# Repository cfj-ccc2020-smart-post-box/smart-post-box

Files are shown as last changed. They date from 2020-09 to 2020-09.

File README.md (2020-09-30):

# Welcome to smart-post-box 👋










> Code for Japan - Civictech Challenge Cup 2020 Team:ARROW It's using ESP-32, Arduino, PlatformIO, Vue, PWA, Express, Slack, LINE, LINE-LIFF, TypeScript ...etc

### 🏠 [Homepage](https://github.com/cfj-ccc2020-smart-post-box/smart-post-box#readme)

### ✨ [Demo](https://youtu.be/A8zUHC4ug6E)

## Prerequisites

- node >=12.18.3
- yarn >=1.22.4

## Install

```sh
yarn install
```

## Usage

```sh
yarn run start
```

## Run tests

```sh
yarn run test
```

## Author

👤 **waricoma <waricoma@devne.co>**

* Website: https://3n38.app
* Twitter: [@waritocomatta](https://twitter.com/waritocomatta)
* Github: [@cfj-ccc2020-smart-post-box](https://github.com/cfj-ccc2020-smart-post-box)
* LinkedIn: [@motone-adachi-b92955145](https://linkedin.com/in/motone-adachi-b92955145)

## 🤝 Contributing

Contributions, issues and feature requests are welcome!

Feel free to check [issues page](https://github.com/cfj-ccc2020-smart-post-box/smart-post-box/issues). You can also take a look at the [contributing guide](https://github.com/cfj-ccc2020-smart-post-box/smart-post-box/blob/master/CONTRIBUTING.md).

## Show your support

Give a ⭐️ if this project helped you!

## 📝 License

Copyright © 2020 [waricoma <waricoma@devne.co>](https://github.com/cfj-ccc2020-smart-post-box).

This project is [GPL--2.0--only](https://github.com/cfj-ccc2020-smart-post-box/smart-post-box/blob/master/LICENSE) licensed.

***
_This README was generated with ❤️ by [readme-md-generator](https://github.com/kefranabg/readme-md-generator)_

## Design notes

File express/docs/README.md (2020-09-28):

**smart-post-box-express**

> README / [Globals](globals.md)

# Welcome to smart-post-box-express 👋








> smart-post-box-express

### 🏠 [Homepage](https://github.com/smart-post-box/smart-post-box#readme)

## Prerequisites

- node >=12.18.3
- yarn >=1.22.4

## Install

```sh
yarn install
```

## Usage

```sh
yarn run start
```

## Run tests

```sh
yarn run test
```

## Author

👤 **waricoma <waricoma@devne.co>**

* Website: https://www.wantedly.com/id/motone_adachi
* Twitter: [@waritocomatta](https://twitter.com/waritocomatta)
* Github: [@waricoma](https://github.com/waricoma)
* LinkedIn: [@motone-adachi-b92955145](https://linkedin.com/in/motone-adachi-b92955145)

## 🤝 Contributing

Contributions, issues and feature requests are welcome!

Feel free to check [issues page](https://github.com/smart-post-box/smart-post-box/issues). You can also take a look at the [contributing guide](https://github.com/smart-post-box/smart-post-box/blob/master/CONTRIBUTING.md).

## Show your support

Give a ⭐️ if this project helped you!

## 📝 License

Copyright © 2020 [waricoma <waricoma@devne.co>](https://github.com/waricoma).

This project is [GPL--2.0--only](https://github.com/smart-post-box/smart-post-box/blob/master/LICENSE) licensed.

***
_This README was generated with ❤️ by [readme-md-generator](https://github.com/kefranabg/readme-md-generator)_

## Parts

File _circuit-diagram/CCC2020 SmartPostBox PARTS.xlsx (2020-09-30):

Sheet: About
Rank | Model | Price: 0000 JPY | Processor | Sensor | Battery | Connection | Warning
Standard | SP-E-M-S-W | Price: 1458.65476190476 | ESP | Magnet | Small | WiFi | It's for the post box of having a lid. You need to prepare two AA size cells.
Standard | SP-E-I-S-W | Price: 1470.02380952381 | ESP | Infrared | Small | WiFi | You need to prepare two AA size cells.
Plus | SP-E-M-S-WM | Price: 2243.21428571429 | ESP | Magnet | Small | WiFi + Mobile Connection | It's for the post box of having a lid. You need to prepare the mobile router, 12V battery charger.
Plus | SP-E-I-S-WM | Price: 2258.39285714286 | ESP | Infrared | Small | WiFi + Mobile Connection | You need to prepare the mobile router, 12V battery charger.
Plus | SP-EM-I-S-W | Price: 3652.02380952381 | ESP+M5Camera | Infrared | Small | WiFi | You need to prepare two AA size cells.
Standard | SP-E-M-B-W | Price: 3661.11904761905 | ESP | Magnet | Big | WiFi | It's for the post box of having a lid. You need to prepare two AA size cells.
Standard | SP-E-I-B-W | Price: 3672.4880952381 | ESP | Infrared | Big | WiFi | You need to prepare two AA size cells.
Plus | SP-EM-M-S-W | Price: 3850.65476190476 | ESP+M5Camera | Magnet | Small | WiFi | It's for the post box of having a lid. You need to prepare two AA size cells.
Plus | SP-E-I-B-WM | Price: 4435.85714285714 | ESP | Infrared | Big | WiFi + Mobile Connection | You need to prepare the mobile router, 12V battery charger.
Pro | SP-EM-I-S-WM | Price: 4475.39285714286 | ESP+M5Camera | Infrared | Small | WiFi + Mobile Connection | You need to prepare the mobile router, 12V battery charger.
Plus | SP-E-M-B-WM | Price: 4480.67857142857 | ESP | Magnet | Big | WiFi + Mobile Connection | It's for the post box of having a lid. You need to prepare the mobile router, 12V battery charger.
Pro | SP-EM-M-S-WM | Price: 4495.21428571429 | ESP+M5Camera | Magnet | Small | WiFi + Mobile Connection | It's for the post box of having a lid. You need to prepare the mobile router, 12V battery charger.
Plus | SP-EM-M-B-W | Price: 5878.11904761905 | ESP+M5Camera | Magnet | Big | WiFi | It's for the post box of having a lid. You need to prepare two AA size cells.
Plus | SP-EM-I-B-W | Price: 5889.4880952381 | ESP+M5Camera | Infrared | Big | WiFi | You need to prepare two AA size cells.
Pro | SP-EM-M-B-WM | Price: 6587.67857142857 | ESP+M5Camera | Magnet | Big | WiFi + Mobile Connection | It's for the post box of having a lid. You need to prepare the mobile router, 12V battery charger.
Pro | SP-EM-I-B-WM | Price: 6602.85714285714 | ESP+M5Camera | Infrared | Big | WiFi + Mobile Connection | You need to prepare the mobile router, 12V battery charger.

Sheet: Parts categories
Body & Sensor
Sensor
Body
Mobile connection
Battery
Sensor & Mobile connection
Camera

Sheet: SP-E-M-S-W
Category | Goods name | Including parts count | Provider | A price of goods | Parts count | Price: 1458.65476190476 | Warning
Sensor | ﾘｰﾄﾞｽｲｯﾁ | 5 | https://akizukidenshi.com/catalog/g/gP-03676/ | 200 | 1 | 40
Body | ピンソケット | 42 | https://akizukidenshi.com/catalog/g/gC-05779/ | 80 | 22 | 41.9047619 | 20 this parts for ESP-WROOM-2, Two this parts for the sensor as body.
Sensor | ピンヘッダ | 40 | https://akizukidenshi.com/catalog/g/gC-00167/ | 35 | 2 | 1.75
Body | ESP-WROOM-2 | 1 | https://akizukidenshi.com/catalog/g/gK-12236/ | 1280 | 1 | 1280
Body | 基板 | 1 | https://akizukidenshi.com/catalog/g/gP-00517/ | 60 | 1 | 60
Battery | 単3電池ボックス | 1 | https://akizukidenshi.com/catalog/g/gP-10197/ | 35 | 1 | 35

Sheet: SP-E-M-S-WM
Category | Goods name | Including parts count | Provider | A price of goods | Parts count | Price: 2243.21428571429 | Warning
Sensor | ﾘｰﾄﾞｽｲｯﾁ | 5 | https://akizukidenshi.com/catalog/g/gP-03676/ | 200 | 1 | 40
Body & Sensor | ピンソケット | 42 | https://akizukidenshi.com/catalog/g/gC-05779/ | 80 | 24 | 45.71428571 | 20 this parts for ESP-WROOM-2, Two this parts for the sensor as body, Two this parts for the mobile connection as body.
Sensor & Mobile connection | ピンヘッダ | 40 | https://akizukidenshi.com/catalog/g/gC-00167/ | 35 | 4 | 3.5 | Two this parts for the sensor, Two this parts for the mobile connection.
Body | ESP-WROOM-2 | 1 | https://akizukidenshi.com/catalog/g/gK-12236/ | 1280 | 1 | 1280
Body | 基板 | 1 | https://akizukidenshi.com/catalog/g/gP-00517/ | 60 | 1 | 60
Mobile connection | ソレノイド | 1 | https://akizukidenshi.com/catalog/g/gP-10761/ | 450 | 1 | 450
Body | 昇圧回路 / USB Connector 単3電池ボックス | 1 | 100-yen shop | 110 | 1 | 110
Mobile connection | USB ケーブル | 1 | 100-yen shop | 110 | 1 | 110
Body | リレー | 1 | https://akizukidenshi.com/catalog/g/gP-07651/ | 60 | 2 | 120 | for mobile connection, Solenoid.
Body | ダイオード | 20 | https://akizukidenshi.com/catalog/g/gI-08327/ | 100 | 2 | 10 | for using relay.
Body | トランジスタ | 20 | https://akizukidenshi.com/catalog/g/gI-13491/ | 100 | 2 | 10 | for using relay.
Body | 10kΩ | 100 | https://akizukidenshi.com/catalog/g/gR-07838/ | 100 | 4 | 4 | for using relay.

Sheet: SP-E-M-B-W
Category | Goods name | Including parts count | Provider | A price of goods | Parts count | Price: 3661.11904761905 | Warning
Sensor | ﾘｰﾄﾞｽｲｯﾁ | 5 | https://akizukidenshi.com/catalog/g/gP-03676/ | 200 | 1 | 40
Body | ピンソケット | 42 | https://akizukidenshi.com/catalog/g/gC-05779/ | 80 | 25 | 47.61904762 | 20 this parts for ESP-WROOM-2, 3 this parts for the voltage down converter, Two this parts for the sensor as body.
Sensor | ピンヘッダ | 40 | https://akizukidenshi.com/catalog/g/gC-00167/ | 35 | 4 | 3.5 | Two this parts for the voltage down converter, Two this parts for the sensor.
Body | ESP-WROOM-2 | 1 | https://akizukidenshi.com/catalog/g/gK-12236/ | 1280 | 1 | 1280
Body | 基板 | 1 | https://akizukidenshi.com/catalog/g/gP-00517/ | 60 | 1 | 60
Battery | 鉛蓄電池 | 1 | https://akizukidenshi.com/catalog/g/gB-04961/ | 1600 | 1 | 1600
Battery | ファストン端子 | 1 | https://akizukidenshi.com/catalog/g/gC-13510/ | 10 | 2 | 20
Battery | 2.1mmプラグ | 1 | https://akizukidenshi.com/catalog/g/gC-02108/ | 60 | 1 | 60
Battery | 2.1mmジャック | 1 | https://akizukidenshi.com/catalog/g/gC-06342/ | 60 | 1 | 60
Battery | DCDC | 1 | https://akizukidenshi.com/catalog/g/gK-09981/ | 450 | 1 | 450
Battery | ヒートシンク | 1 | https://akizukidenshi.com/catalog/g/gP-05053/ | 40 | 1 | 40

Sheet: SP-E-M-B-WM
Category | Goods name | Including parts count | Provider | A price of goods | Parts count | Price: 4480.67857142857 | Warning
Sensor | ﾘｰﾄﾞｽｲｯﾁ | 5 | https://akizukidenshi.com/catalog/g/gP-03676/ | 200 | 1 | 40
Body | ピンソケット | 42 | https://akizukidenshi.com/catalog/g/gC-05779/ | 80 | 27 | 51.42857143 | 20 this parts for ESP-WROOM-2, 3 this parts for the voltage down converter, Two this parts for the sensor as body, Two this parts for the mobile connection as body.
Sensor & Mobile connection | ピンヘッダ | 40 | https://akizukidenshi.com/catalog/g/gC-00167/ | 35 | 6 | 5.25 | Two this parts for the sensor, Two this parts for the voltage down converter, Two this parts for the mobile connection.
Body | ESP-WROOM-2 | 1 | https://akizukidenshi.com/catalog/g/gK-12236/ | 1280 | 1 | 1280
Body | 基板 | 1 | https://akizukidenshi.com/catalog/g/gP-00517/ | 60 | 1 | 60
Battery | 鉛蓄電池 | 1 | https://akizukidenshi.com/catalog/g/gB-04961/ | 1600 | 1 | 1600
Battery | ファストン端子 | 1 | https://akizukidenshi.com/catalog/g/gC-13510/ | 10 | 2 | 20
Battery | 2.1mmプラグ | 1 | https://akizukidenshi.com/catalog/g/gC-02108/ | 60 | 1 | 60
Battery | 2.1mmジャック | 1 | https://akizukidenshi.com/catalog/g/gC-06342/ | 60 | 1 | 60
Battery | DCDC | 1 | https://akizukidenshi.com/catalog/g/gK-09981/ | 450 | 1 | 450
Battery | ヒートシンク | 1 | https://akizukidenshi.com/catalog/g/gP-05053/ | 40 | 1 | 40
Mobile connection | ソレノイド | 1 | https://akizukidenshi.com/catalog/g/gP-10761/ | 450 | 1 | 450
Body | 昇圧回路 / USBコネクタ | 1 | 100-yen shop | 110 | 1 | 110
Mobile connection | USB ケーブル | 1 | 100-yen shop | 110 | 1 | 110
Body | リレー | 1 | https://akizukidenshi.com/catalog/g/gP-07651/ | 60 | 2 | 120 | for mobile connection, Solenoid.
Body | ダイオード | 20 | https://akizukidenshi.com/catalog/g/gI-08327/ | 100 | 2 | 10 | for using relay.
Body | トランジスタ | 20 | https://akizukidenshi.com/catalog/g/gI-13491/ | 100 | 2 | 10 | for using relay.
Body | 10kΩ | 100 | https://akizukidenshi.com/catalog/g/gR-07838/ | 100 | 4 | 4 | for using relay.

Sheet: SP-E-I-S-W
Category | Goods name | Including parts count | Provider | A price of goods | Parts count | Price: 1470.02380952381 | Warning
Sensor | 赤外線LED | 5 | https://akizukidenshi.com/catalog/g/gI-03261/ | 100 | 1 | 20 | If your post box is large, We recommend changing the number of "Parts count" to 3. Because one sensor will be three sensors.
Sensor | フォトトランジスタ | 10 | https://akizukidenshi.com/catalog/g/gI-04213/ | 200 | 1 | 20 | If your post box is large, We recommend changing the number of ""Parts count"" to 3. Because one sensor will be three sensors.
Sensor | 抵抗50Ω | 100 | https://akizukidenshi.com/catalog/g/gR-07803/ | 100 | 1 | 1 | If your post box is large, We recommend changing the number of ""Parts count"" to 3. Because one sensor will be three sensors.
Sensor | 抵抗4.7kΩ | 100 | https://akizukidenshi.com/catalog/g/gR-07831/ | 100 | 1 | 1 | If your post box is large, We recommend changing the number of "Parts count" to 6. Because one sensor will be three sensors.
Body & Sensor | ピンソケット | 42 | https://akizukidenshi.com/catalog/g/gC-05779/ | 80 | 26 | 49.52380952 | 20 this parts for ESP-WROOM-2, 4 this parts for body, 4 this parts for one sensor. If your post box is large, We recommend changing the number of "Parts count" to 52. Because one sensor will be three sensors.
Sensor | ピンヘッダ | 40 | https://akizukidenshi.com/catalog/g/gC-00167/ | 35 | 4 | 3.5 | If your post box is large, We recommend changing the number of "Parts count" to 12. Because one sensor will be three sensors.
Body | ESP-WROOM-2 | 1 | https://akizukidenshi.com/catalog/g/gK-12236/ | 1280 | 1 | 1280
Body & Sensor | 基板 | 1 | https://akizukidenshi.com/catalog/g/gP-00517/ | 60 | 1 | 60 | If your post box is large, We recommend changing the number of ""Parts count"" to 2.
Battery | 単3電池ボックス | 1 | https://akizukidenshi.com/catalog/g/gP-10197/ | 35 | 1 | 35

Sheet: SP-E-I-S-WM
Category | Goods name | Including parts count | Provider | A price of goods | Parts count | Price: 2258.39285714286 | Warning
Sensor | 赤外線LED | 5 | https://akizukidenshi.com/catalog/g/gI-03261/ | 100 | 1 | 20 | If your post box is large, We recommend changing the number of "Parts count" to 3. Because one sensor will be three sensors.
Sensor | フォトトランジスタ | 10 | https://akizukidenshi.com/catalog/g/gI-04213/ | 200 | 1 | 20 | "If your post box is large, We recommend changing the number of ""Parts count"" to 3. Because one sensor will be three sensors."
Sensor | 抵抗50Ω | 100 | https://akizukidenshi.com/catalog/g/gR-07803/ | 100 | 1 | 1 | "If your post box is large, We recommend changing the number of ""Parts count"" to 3. Because one sensor will be three sensors."
Sensor | 抵抗4.7kΩ | 100 | https://akizukidenshi.com/catalog/g/gR-07831/ | 100 | 1 | 1 | If your post box is large, We recommend changing the number of "Parts count" to 6. Because one sensor will be three sensors.
Body & Sensor | ピンソケット | 42 | https://akizukidenshi.com/catalog/g/gC-05779/ | 80 | 30 | 57.14285714 | 20 this parts for ESP-WROOM-2, 4 this parts for body, 4 this parts for one sensor, two this parts for the mobile connection. If your post box is large, We recommend changing the number of "Parts count" to 54. Because one sensor will be three sensors.
Sensor & Mobile connection | ピンヘッダ | 40 | https://akizukidenshi.com/catalog/g/gC-00167/ | 35 | 6 | 5.25 | 4 this parts for the sensor, Two this parts for the mobile connection. If your post box is large, We recommend changing the number of "Parts count" to 14. Because one sensor will be three sensors.
Body | ESP-WROOM-2 | 1 | https://akizukidenshi.com/catalog/g/gK-12236/ | 1280 | 1 | 1280
Body & Sensor | 基板 | 1 | https://akizukidenshi.com/catalog/g/gP-00517/ | 60 | 1 | 60 | If your post box is large, We recommend changing the number of ""Parts count"" to 2.
Mobile connection | ソレノイド | 1 | https://akizukidenshi.com/catalog/g/gP-10761/ | 450 | 1 | 450
Body | 昇圧回路 / USB Connector 単3電池ボックス | 1 | 100-yen shop | 110 | 1 | 110
Mobile connection | USB Cable | 1 | 100-yen shop | 110 | 1 | 110
Body | リレー | 1 | https://akizukidenshi.com/catalog/g/gP-07651/ | 60 | 2 | 120 | for mobile connection, Solenoid.
Body | ダイオード | 20 | https://akizukidenshi.com/catalog/g/gI-08327/ | 100 | 2 | 10 | for using relay.
Body | トランジスタ | 20 | https://akizukidenshi.com/catalog/g/gI-13491/ | 100 | 2 | 10 | for using relay.
Body | 10kΩ | 100 | https://akizukidenshi.com/catalog/g/gR-07838/ | 100 | 4 | 4 | for using relay.

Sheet: SP-E-I-B-W
Category | Goods name | Including parts count | Provider | A price of goods | Parts count | Price: 3672.4880952381 | Warning
Sensor | 赤外線LED | 5 | https://akizukidenshi.com/catalog/g/gI-03261/ | 100 | 1 | 20 | If your post box is large, We recommend changing the number of "Parts count" to 3. Because one sensor will be three sensors.
Sensor | フォトトランジスタ | 10 | https://akizukidenshi.com/catalog/g/gI-04213/ | 200 | 1 | 20 | "If your post box is large, We recommend changing the number of ""Parts count"" to 3. Because one sensor will be three sensors."
Sensor | 抵抗50Ω | 100 | https://akizukidenshi.com/catalog/g/gR-07803/ | 100 | 1 | 1 | "If your post box is large, We recommend changing the number of ""Parts count"" to 3. Because one sensor will be three sensors."
Sensor | 抵抗4.7kΩ | 100 | https://akizukidenshi.com/catalog/g/gR-07831/ | 100 | 1 | 1 | If your post box is large, We recommend changing the number of "Parts count" to 6. Because one sensor will be three sensors.
Body & Sensor | ピンソケット | 42 | https://akizukidenshi.com/catalog/g/gC-05779/ | 80 | 29 | 55.23809524 | 20 this parts for ESP-WROOM-2, 4 this parts for body, 4 this parts for one sensor, 3 this parts for the voltage down converter. If your post box is large, We recommend changing the number of "Parts count" to 55. Because one sensor will be three sensors.
Body & Sensor | ピンヘッダ | 40 | https://akizukidenshi.com/catalog/g/gC-00167/ | 35 | 6 | 5.25 | Two this parts for the voltage down converter, 4 this parts for one sensor. If your post box is large, We recommend changing the number of "Parts count" to 14. Because one sensor will be three sensors.
Body | ESP-WROOM-2 | 1 | https://akizukidenshi.com/catalog/g/gK-12236/ | 1280 | 1 | 1280
Body & Sensor | 基板 | 1 | https://akizukidenshi.com/catalog/g/gP-00517/ | 60 | 1 | 60 | If your post box is large, We recommend changing the number of ""Parts count"" to 2.
Battery | 鉛蓄電池 | 1 | https://akizukidenshi.com/catalog/g/gB-04961/ | 1600 | 1 | 1600
Battery | ファストン端子 | 1 | https://akizukidenshi.com/catalog/g/gC-13510/ | 10 | 2 | 20
Battery | 2.1mmプラグ | 1 | https://akizukidenshi.com/catalog/g/gC-02108/ | 60 | 1 | 60
Battery | 2.1mmジャック | 1 | https://akizukidenshi.com/catalog/g/gC-06342/ | 60 | 1 | 60
Battery | DCDC | 1 | https://akizukidenshi.com/catalog/g/gK-09981/ | 450 | 1 | 450
Battery | ヒートシンク | 1 | https://akizukidenshi.com/catalog/g/gP-05053/ | 40 | 1 | 40

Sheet: SP-E-I-B-WM
Category | Goods name | Including parts count | Provider | A price of goods | Parts count | Price: 4435.85714285714 | Warning
Sensor | 赤外線LED | 5 | https://akizukidenshi.com/catalog/g/gI-03261/ | 100 | 1 | 20 | If your post box is large, We recommend changing the number of "Parts count" to 3. Because one sensor will be three sensors.
Sensor | フォトトランジスタ | 10 | https://akizukidenshi.com/catalog/g/gI-04213/ | 200 | 1 | 20 | If your post box is large, We recommend changing the number of ""Parts count"" to 3. Because one sensor will be three sensors.
Sensor | 抵抗50Ω | 100 | https://akizukidenshi.com/catalog/g/gR-07803/ | 100 | 1 | 1 | If your post box is large, We recommend changing the number of ""Parts count"" to 3. Because one sensor will be three sensors
Sensor | 抵抗4.7kΩ | 100 | https://akizukidenshi.com/catalog/g/gR-07831/ | 100 | 1 | 1 | If your post box is large, We recommend changing the number of "Parts count" to 6. Because one sensor will be three sensors.
Body & Sensor | ピンソケット | 42 | https://akizukidenshi.com/catalog/g/gC-05779/ | 80 | 33 | 62.85714286 | 20 this parts for ESP-WROOM-2, 4 this parts for body, 4 this parts for one sensor, Two this parts for the mobile connection, 3 this parts for the voltage down converter. If your post box is large, We recommend changing the number of "Parts count" to 57. Because one sensor will be three sensors.
Sensor & Mobile connection | ピンヘッダ | 40 | https://akizukidenshi.com/catalog/g/gC-00167/ | 35 | 8 | 7 | 4 this parts for the sensor, Two this parts for the mobile connection, Two this parts for the voltage down converter. If your post box is large, We recommend changing the number of "Parts count" to 16. Because one sensor will be three sensors.
Body | ESP-WROOM-2 | 1 | https://akizukidenshi.com/catalog/g/gK-12236/ | 1280 | 1 | 1280
Battery | 鉛蓄電池 | 1 | https://akizukidenshi.com/catalog/g/gB-04961/ | 1600 | 1 | 1600
Battery | ファストン端子 | 1 | https://akizukidenshi.com/catalog/g/gC-13510/ | 10 | 2 | 20
Body & Sensor | 基板 | 1 | https://akizukidenshi.com/catalog/g/gP-00517/ | 60 | 1 | 60 | If your post box is large, We recommend changing the number of ""Parts count"" to 2.
Battery | 2.1mmジャック | 1 | https://akizukidenshi.com/catalog/g/gC-06342/ | 60 | 1 | 60
Battery | DCDC | 1 | https://akizukidenshi.com/catalog/g/gK-09981/ | 450 | 1 | 450
Battery | ヒートシンク | 1 | https://akizukidenshi.com/catalog/g/gP-05053/ | 40 | 1 | 40
Mobile connection | ソレノイド | 1 | https://akizukidenshi.com/catalog/g/gP-10761/ | 450 | 1 | 450
Body | 昇圧回路 / USBコネクタ | 1 | 100-yen shop | 110 | 1 | 110
Mobile connection | USB ケーブル | 1 | 100-yen shop | 110 | 1 | 110
Body | リレー | 1 | https://akizukidenshi.com/catalog/g/gP-07651/ | 60 | 2 | 120 | for mobile connection, Solenoid.
Body | ダイオード | 20 | https://akizukidenshi.com/catalog/g/gI-08327/ | 100 | 2 | 10 | for using relay.
Body | トランジスタ | 20 | https://akizukidenshi.com/catalog/g/gI-13491/ | 100 | 2 | 10 | for using relay.
Body | 10kΩ | 100 | https://akizukidenshi.com/catalog/g/gR-07838/ | 100 | 4 | 4 | for using relay.

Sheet: SP-EM-M-S-W
Category | Goods name | Including parts count | Provider | A price of goods | Parts count | Price: 3850.65476190476 | Warning
Sensor | ﾘｰﾄﾞｽｲｯﾁ | 1 | https://akizukidenshi.com/catalog/g/gP-13371/ | 250 | 1 | 250
Body | ピンソケット | 42 | https://akizukidenshi.com/catalog/g/gC-05779/ | 80 | 22 | 41.9047619 | 20 this parts for ESP-WROOM-2, Two this parts for the sensor as body.
Sensor | ピンヘッダ | 40 | https://akizukidenshi.com/catalog/g/gC-00167/ | 35 | 2 | 1.75
Body | ESP-WROOM-2 | 1 | https://akizukidenshi.com/catalog/g/gK-12236/ | 1280 | 1 | 1280
Body | 基板 | 1 | https://akizukidenshi.com/catalog/g/gP-00517/ | 60 | 1 | 60
Body | 昇圧回路 / USB Connector 単3電池ボックス | 1 | 100-yen shop | 110 | 1 | 110
Camera | M5Camera | 1 | https://www.switch-science.com/catalog/5207/ | 2035 | 1 | 2035
Body | リレー | 1 | https://akizukidenshi.com/catalog/g/gP-07651/ | 60 | 1 | 60 | to control m5camera.
Body | ダイオード | 20 | https://akizukidenshi.com/catalog/g/gI-08327/ | 100 | 1 | 5 | for using relay.
Body | トランジスタ | 20 | https://akizukidenshi.com/catalog/g/gI-13491/ | 100 | 1 | 5 | for using relay.
Body | 10kΩ | 100 | https://akizukidenshi.com/catalog/g/gR-07838/ | 100 | 2 | 2 | for using relay.

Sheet: SP-EM-M-S-WM
Category | Goods name | Including parts count | Provider | A price of goods | Parts count | Price: 4495.21428571429 | Warning
Sensor | ﾘｰﾄﾞｽｲｯﾁ | 5 | https://akizukidenshi.com/catalog/g/gP-03676/ | 200 | 1 | 40
Body & Sensor | ピンソケット | 42 | https://akizukidenshi.com/catalog/g/gC-05779/ | 80 | 24 | 45.71428571 | 20 this parts for ESP-WROOM-2, Two this parts for the sensor as body, Two this parts for the mobile connection as body.
Sensor & Mobile connection | ピンヘッダ | 40 | https://akizukidenshi.com/catalog/g/gC-00167/ | 35 | 4 | 3.5 | Two this parts for the sensor, Two this parts for the mobile connection.
Body | ESP-WROOM-2 | 1 | https://akizukidenshi.com/catalog/g/gK-12236/ | 1280 | 1 | 1280
Body | 基板 | 1 | https://akizukidenshi.com/catalog/g/gP-00517/ | 60 | 1 | 60
Battery | 単3電池ボックス | 1 | https://akizukidenshi.com/catalog/g/gP-10197/ | 35 | 1 | 35
Mobile connection | ソレノイド | 1 | https://akizukidenshi.com/catalog/g/gP-10761/ | 450 | 1 | 450
Body | 昇圧回路 / USB Connector | 1 | 100-yen shop | 110 | 2 | 220 | for mobile connection, M5camera.
Mobile connection | USB ケーブル | 1 | 100-yen shop | 110 | 1 | 110
Camera | M5Camera | 1 | https://www.switch-science.com/catalog/5207/ | 2035 | 1 | 2035
Body | リレー | 1 | https://akizukidenshi.com/catalog/g/gP-07651/ | 60 | 3 | 180 | for mobile connection, Solenoid, M5camera.
Body | ダイオード | 20 | https://akizukidenshi.com/catalog/g/gI-08327/ | 100 | 3 | 15 | for using relay.
Body | トランジスタ | 20 | https://akizukidenshi.com/catalog/g/gI-13491/ | 100 | 3 | 15 | for using relay.
Body | 10kΩ | 100 | https://akizukidenshi.com/catalog/g/gR-07838/ | 100 | 6 | 6 | for using relay.

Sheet: SP-EM-M-B-W
Category | Goods name | Including parts count | Provider | A price of goods | Parts count | Price: 5878.11904761905 | Warning
Sensor | ﾘｰﾄﾞｽｲｯﾁ | 5 | https://akizukidenshi.com/catalog/g/gP-03676/ | 200 | 1 | 40
Body | ピンソケット | 42 | https://akizukidenshi.com/catalog/g/gC-05779/ | 80 | 25 | 47.61904762 | 20 this parts for ESP-WROOM-2, 3 this parts for the voltage down converter, Two this parts for the sensor as body.
Sensor | ピンヘッダ | 40 | https://akizukidenshi.com/catalog/g/gC-00167/ | 35 | 4 | 3.5 | Two this parts for the voltage down converter, Two this parts for the sensor.
Body | ESP-WROOM-2 | 1 | https://akizukidenshi.com/catalog/g/gK-12236/ | 1280 | 1 | 1280
Body | 基板 | 1 | https://akizukidenshi.com/catalog/g/gP-00517/ | 60 | 1 | 60
Battery | 鉛蓄電池 | 1 | https://akizukidenshi.com/catalog/g/gB-04961/ | 1600 | 1 | 1600
Battery | ファストン端子 | 1 | https://akizukidenshi.com/catalog/g/gC-13510/ | 10 | 2 | 20
Battery | 2.1mmプラグ | 1 | https://akizukidenshi.com/catalog/g/gC-02108/ | 60 | 1 | 60
Battery | 2.1mmジャック | 1 | https://akizukidenshi.com/catalog/g/gC-06342/ | 60 | 1 | 60
Battery | DCDC | 1 | https://akizukidenshi.com/catalog/g/gK-09981/ | 450 | 1 | 450
Battery | ヒートシンク | 1 | https://akizukidenshi.com/catalog/g/gP-05053/ | 40 | 1 | 40
Camera | M5Camera | 1 | https://www.switch-science.com/catalog/5207/ | 2035 | 1 | 2035
Body | 昇圧回路 / USB Connector | 1 | 100-yen shop | 110 | 1 | 110
Body | リレー | 1 | https://akizukidenshi.com/catalog/g/gP-07651/ | 60 | 1 | 60 | to control m5camera.
Body | ダイオード | 20 | https://akizukidenshi.com/catalog/g/gI-08327/ | 100 | 1 | 5 | for using relay.
Body | トランジスタ | 20 | https://akizukidenshi.com/catalog/g/gI-13491/ | 100 | 1 | 5 | for using relay.
Body | 10kΩ | 100 | https://akizukidenshi.com/catalog/g/gR-07838/ | 100 | 2 | 2 | for using relay.

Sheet: SP-EM-M-B-WM
Category | Goods name | Including parts count | Provider | A price of goods | Parts count | Price: 6587.67857142857 | Warning
Sensor | ﾘｰﾄﾞｽｲｯﾁ | 5 | https://akizukidenshi.com/catalog/g/gP-03676/ | 200 | 1 | 40
Body | ピンソケット | 42 | https://akizukidenshi.com/catalog/g/gC-05779/ | 80 | 27 | 51.42857143 | 20 this parts for ESP-WROOM-2, 3 this parts for the voltage down converter, Two this parts for the sensor as body, Two this parts for the mobile connection as body.
Sensor & Mobile connection | ピンヘッダ | 40 | https://akizukidenshi.com/catalog/g/gC-00167/ | 35 | 6 | 5.25 | Two this parts for the sensor, Two this parts for the voltage down converter, Two this parts for the mobile connection.
Body | ESP-WROOM-2 | 1 | https://akizukidenshi.com/catalog/g/gK-12236/ | 1280 | 1 | 1280
Body | 基板 | 1 | https://akizukidenshi.com/catalog/g/gP-00517/ | 60 | 1 | 60
Battery | 鉛蓄電池 | 1 | https://akizukidenshi.com/catalog/g/gB-04961/ | 1600 | 1 | 1600
Battery | ファストン端子 | 1 | https://akizukidenshi.com/catalog/g/gC-13510/ | 10 | 2 | 20
Battery | 2.1mmプラグ | 1 | https://akizukidenshi.com/catalog/g/gC-02108/ | 60 | 1 | 60
Battery | 2.1mmジャック | 1 | https://akizukidenshi.com/catalog/g/gC-06342/ | 60 | 1 | 60
Battery | DCDC | 1 | https://akizukidenshi.com/catalog/g/gK-09981/ | 450 | 1 | 450
Battery | ヒートシンク | 1 | https://akizukidenshi.com/catalog/g/gP-05053/ | 40 | 1 | 40
Mobile connection | ソレノイド | 1 | https://akizukidenshi.com/catalog/g/gP-10761/ | 450 | 1 | 450
Body | USBハブ | 1 | 100-yen shop | 110 | 1 | 110 | for mobile connection, M5camera.
Mobile connection | USB ケーブル | 1 | 100-yen shop | 110 | 1 | 110
Camera | M5Camera | 1 | https://www.switch-science.com/catalog/5207/ | 2035 | 1 | 2035
Body | リレー | 1 | https://akizukidenshi.com/catalog/g/gP-07651/ | 60 | 3 | 180 | for mobile connection, Solenoid, M5camera.
Body | ダイオード | 20 | https://akizukidenshi.com/catalog/g/gI-08327/ | 100 | 3 | 15 | for using relay.
Body | トランジスタ | 20 | https://akizukidenshi.com/catalog/g/gI-13491/ | 100 | 3 | 15 | for using relay.
Body | 10kΩ | 100 | https://akizukidenshi.com/catalog/g/gR-07838/ | 100 | 6 | 6 | for using relay.

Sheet: SP-EM-I-S-W
Category | Goods name | Including parts count | Provider | A price of goods | Parts count | Price: 3652.02380952381 | Warning
Sensor | 赤外線LED | 5 | https://akizukidenshi.com/catalog/g/gI-03261/ | 100 | 1 | 20 | If your post box is large, We recommend changing the number of "Parts count" to 3. Because one sensor will be three sensors.
Sensor | フォトトランジスタ | 10 | https://akizukidenshi.com/catalog/g/gI-04213/ | 200 | 1 | 20 | "If your post box is large, We recommend changing the number of ""Parts count"" to 3. Because one sensor will be three sensors."
Sensor | 抵抗50Ω | 100 | https://akizukidenshi.com/catalog/g/gR-07803/ | 100 | 1 | 1 | "If your post box is large, We recommend changing the number of ""Parts count"" to 3. Because one sensor will be three sensors."
Sensor | 抵抗4.7kΩ | 100 | https://akizukidenshi.com/catalog/g/gR-07831/ | 100 | 1 | 1 | If your post box is large, We recommend changing the number of "Parts count" to 6. Because one sensor will be three sensors.
Body & Sensor | ピンソケット | 42 | https://akizukidenshi.com/catalog/g/gC-05779/ | 80 | 26 | 49.52380952 | 20 this parts for ESP-WROOM-2, 4 this parts for body, 4 this parts for one sensor. If your post box is large, We recommend changing the number of "Parts count" to 52. Because one sensor will be three sensors.
Sensor | ピンヘッダ | 40 | https://akizukidenshi.com/catalog/g/gC-00167/ | 35 | 4 | 3.5 | If your post box is large, We recommend changing the number of "Parts count" to 12. Because one sensor will be three sensors.
Body | ESP-WROOM-2 | 1 | https://akizukidenshi.com/catalog/g/gK-12236/ | 1280 | 1 | 1280
Body | 昇圧回路 / USB Connector 単3電池ボックス | 1 | 100-yen shop | 110 | 1 | 110
Camera | M5Camera | 1 | https://www.switch-science.com/catalog/5207/ | 2035 | 1 | 2035
Body & Sensor | 基板 | 1 | https://akizukidenshi.com/catalog/g/gP-00517/ | 60 | 1 | 60 | If your post box is large, We recommend changing the number of ""Parts count"" to 2.
Body | リレー | 1 | https://akizukidenshi.com/catalog/g/gP-07651/ | 60 | 1 | 60 | to control m5camera.
Body | ダイオード | 20 | https://akizukidenshi.com/catalog/g/gI-08327/ | 100 | 1 | 5 | for using relay.
Body | トランジスタ | 20 | https://akizukidenshi.com/catalog/g/gI-13491/ | 100 | 1 | 5 | for using relay.
Body | 10kΩ | 100 | https://akizukidenshi.com/catalog/g/gR-07838/ | 100 | 2 | 2 | for using relay.

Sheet: SP-EM-I-S-WM
Category | Goods name | Including parts count | Provider | A price of goods | Parts count | Price: 4475.39285714286 | Warning
Sensor | 赤外線LED | 5 | https://akizukidenshi.com/catalog/g/gI-03261/ | 100 | 1 | 20 | If your post box is large, We recommend changing the number of "Parts count" to 3. Because one sensor will be three sensors.
Sensor | フォトトランジスタ | 10 | https://akizukidenshi.com/catalog/g/gI-04213/ | 200 | 1 | 20 | "If your post box is large, We recommend changing the number of ""Parts count"" to 3. Because one sensor will be three sensors."
Sensor | 抵抗50Ω | 100 | https://akizukidenshi.com/catalog/g/gR-07803/ | 100 | 1 | 1 | "If your post box is large, We recommend changing the number of ""Parts count"" to 3. Because one sensor will be three sensors."
Sensor | 抵抗4.7kΩ | 100 | https://akizukidenshi.com/catalog/g/gR-07831/ | 100 | 1 | 1 | If your post box is large, We recommend changing the number of "Parts count" to 6. Because one sensor will be three sensors.
Body & Sensor | ピンソケット | 42 | https://akizukidenshi.com/catalog/g/gC-05779/ | 80 | 30 | 57.14285714 | 20 this parts for ESP-WROOM-2, 4 this parts for body, 4 this parts for one sensor, two this parts for the mobile connection. If your post box is large, We recommend changing the number of "Parts count" to 54. Because one sensor will be three sensors.
Sensor & Mobile connection | ピンヘッダ | 40 | https://akizukidenshi.com/catalog/g/gC-00167/ | 35 | 6 | 5.25 | 4 this parts for the sensor, Two this parts for the mobile connection. If your post box is large, We recommend changing the number of "Parts count" to 14. Because one sensor will be three sensors.
Body | ESP-WROOM-2 | 1 | https://akizukidenshi.com/catalog/g/gK-12236/ | 1280 | 1 | 1280
Body & Sensor | 基板 | 1 | https://akizukidenshi.com/catalog/g/gP-00517/ | 60 | 1 | 60 | If your post box is large, We recommend changing the number of ""Parts count"" to 2.
Mobile connection | ソレノイド | 1 | https://akizukidenshi.com/catalog/g/gP-10761/ | 450 | 1 | 450
Body | 昇圧回路 / USB Connector 単3電池ボックス | 1 | 100-yen shop | 110 | 2 | 220 | for mobile connection, M5camera.
Mobile connection | USB Cable | 1 | 100-yen shop | 110 | 1 | 110
Camera | M5Camera | 1 | https://www.switch-science.com/catalog/5207/ | 2035 | 1 | 2035
Body | リレー | 1 | https://akizukidenshi.com/catalog/g/gP-07651/ | 60 | 3 | 180 | for mobile connection, Solenoid, M5camera.
Body | ダイオード | 20 | https://akizukidenshi.com/catalog/g/gI-08327/ | 100 | 3 | 15 | for using relay.
Body | トランジスタ | 20 | https://akizukidenshi.com/catalog/g/gI-13491/ | 100 | 3 | 15 | for using relay.
Body | 10kΩ | 100 | https://akizukidenshi.com/catalog/g/gR-07838/ | 100 | 6 | 6 | for using relay.
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

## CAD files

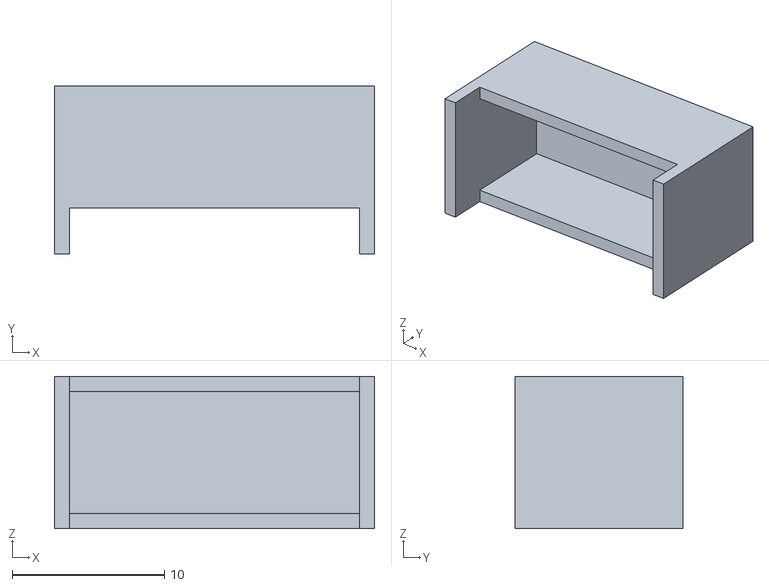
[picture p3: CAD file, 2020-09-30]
_3d-cad/fillParts/underESPSuppress.stl
21.0 x 11.0 x 10.0

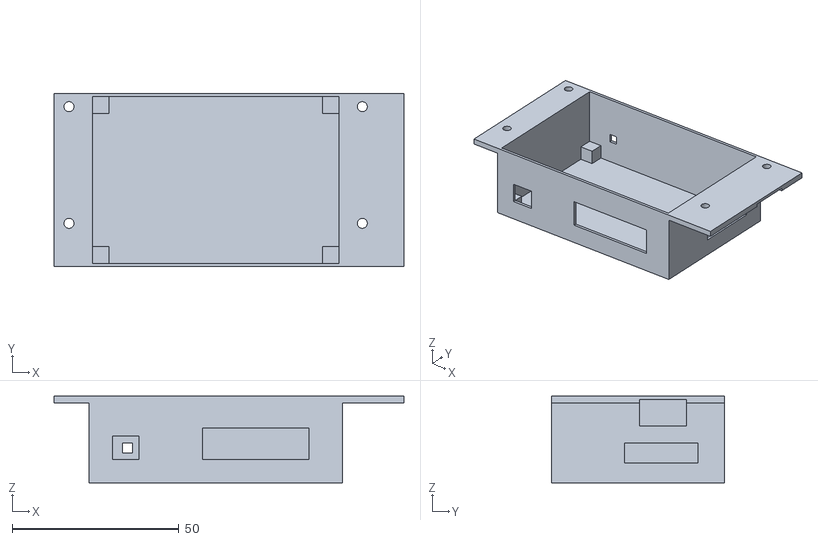
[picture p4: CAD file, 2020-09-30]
_3d-cad/mainbox/box.stl
105.0 x 52.0 x 26.0

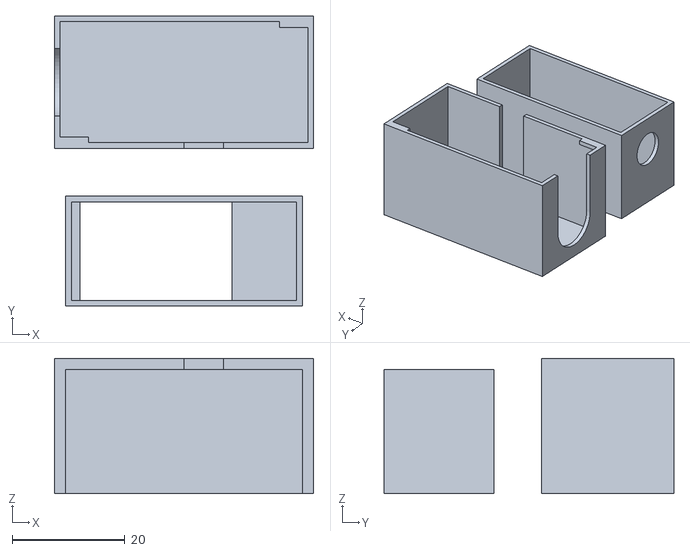
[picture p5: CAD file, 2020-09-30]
_3d-cad/subBox/DCDC.stl
46.0 x 51.5 x 24.0

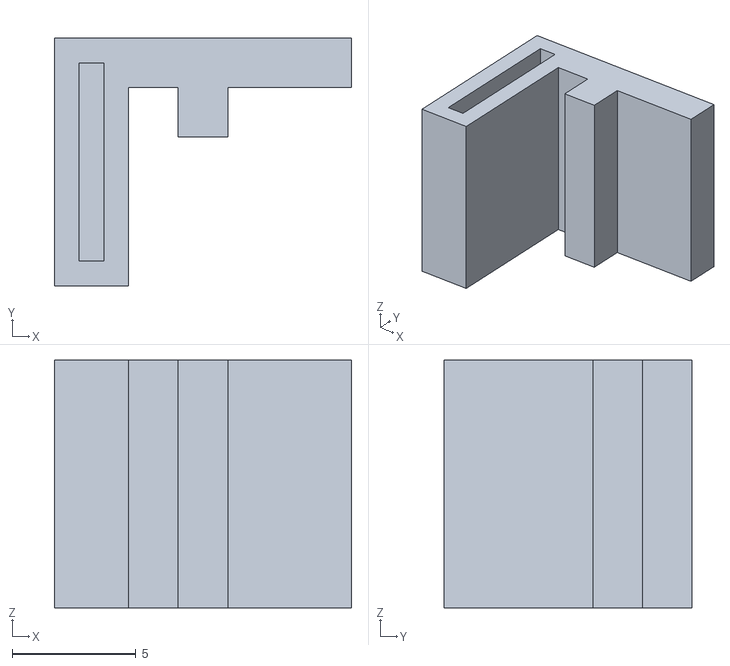
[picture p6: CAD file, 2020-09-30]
_3d-cad/fillParts/lock.stl
12.0 x 10.0 x 10.0

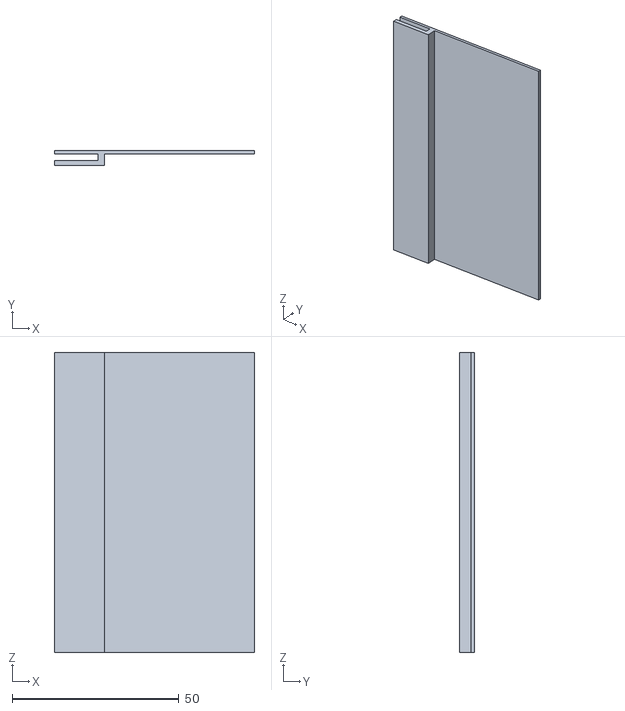
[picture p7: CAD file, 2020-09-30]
_3d-cad/mainbox/roof9.stl
60.0 x 4.50 x 90.0

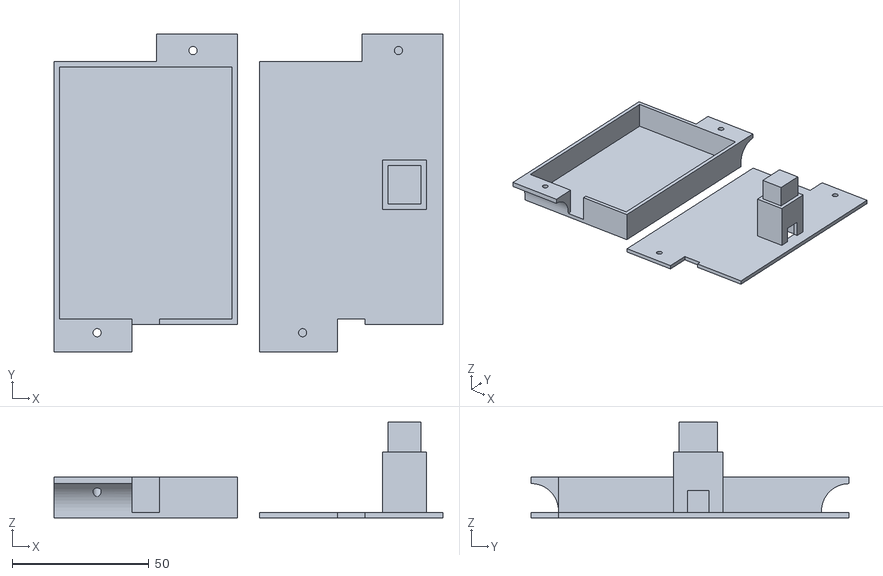
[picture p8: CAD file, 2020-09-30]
_3d-cad/subBox/roter.stl
142.0 x 116.0 x 35.0

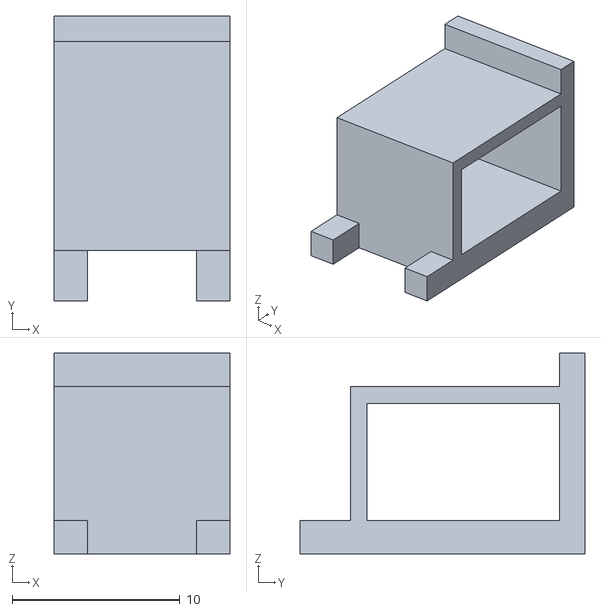
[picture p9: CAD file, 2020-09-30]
_3d-cad/fillParts/2Suppress.stl
10.5 x 17.0 x 12.0

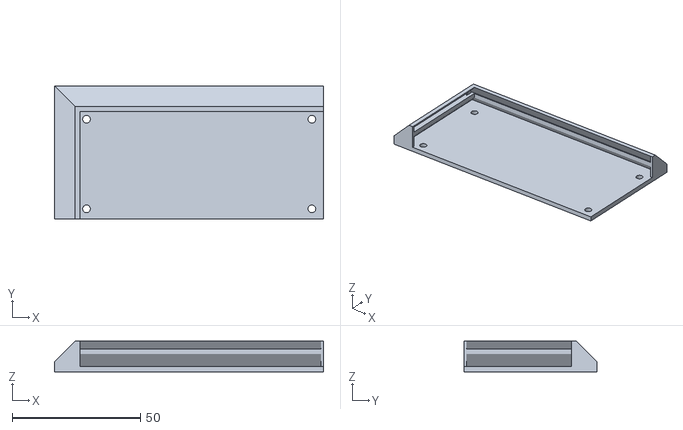
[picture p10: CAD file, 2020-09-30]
_3d-cad/mainbox/cover.stl
105.0 x 52.0 x 12.0

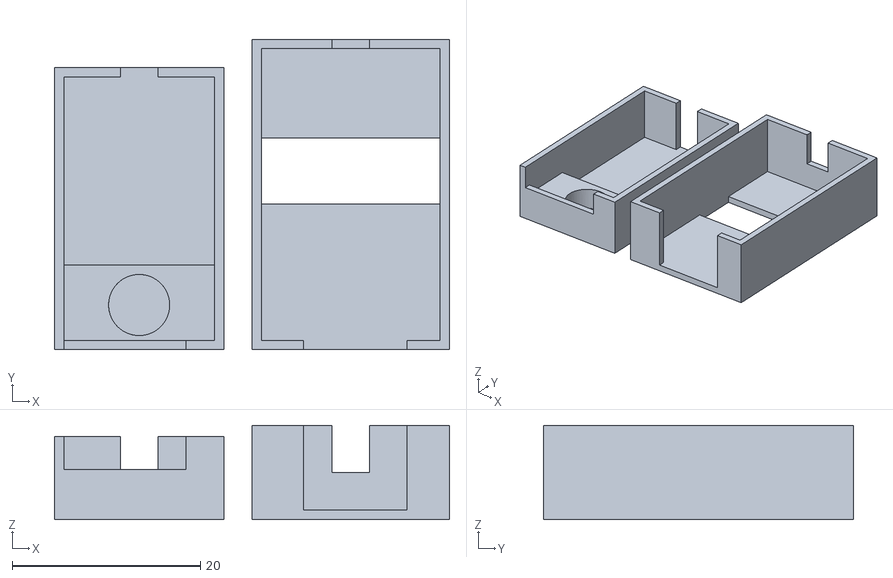
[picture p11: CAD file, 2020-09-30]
_3d-cad/subBox/LED.stl
42.0 x 33.0 x 10.0

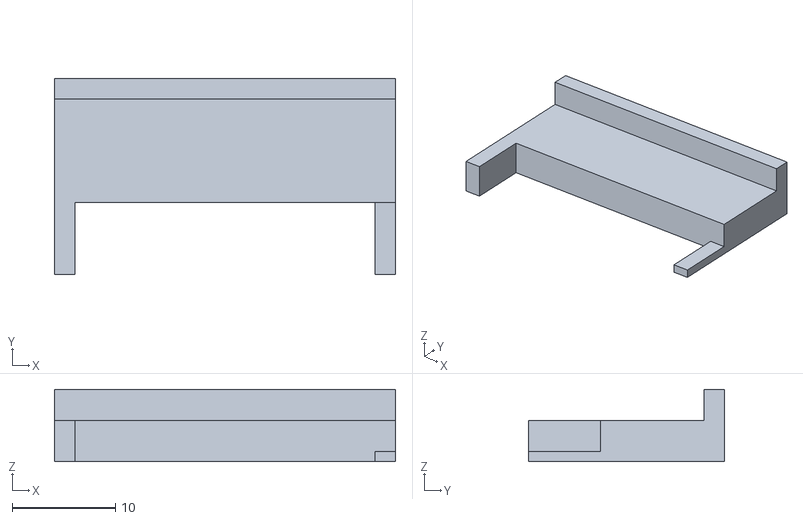
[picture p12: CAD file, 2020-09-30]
_3d-cad/fillParts/USBSuppress.stl
33.0 x 19.0 x 7.00

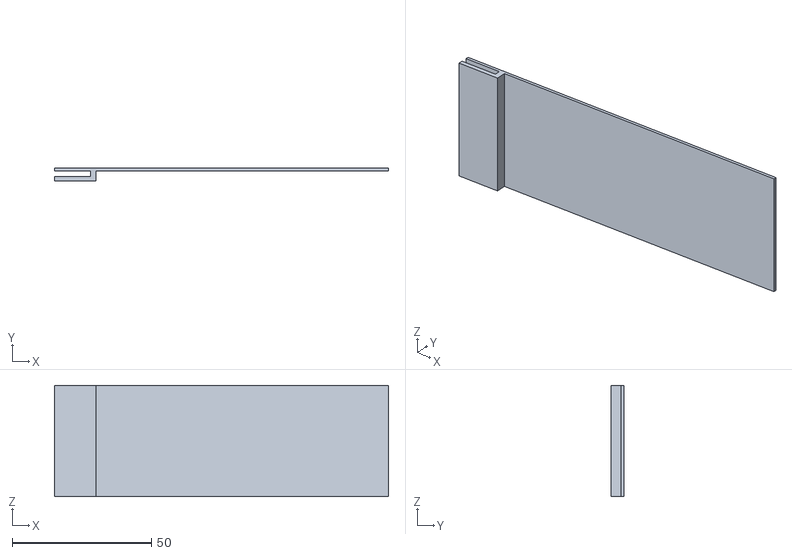
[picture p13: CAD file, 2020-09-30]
_3d-cad/mainbox/roof4.stl
120.0 x 4.50 x 40.0

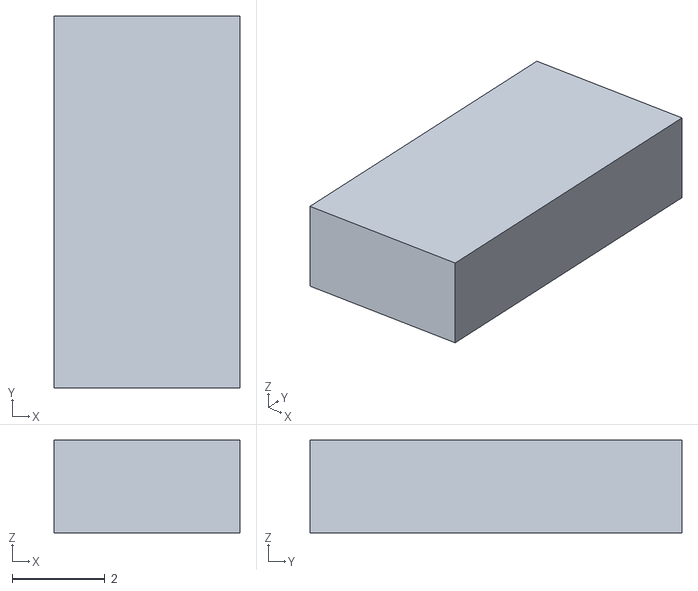
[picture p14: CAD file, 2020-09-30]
_3d-cad/fillParts/USBBackPrate.stl
4.00 x 8.00 x 2.00

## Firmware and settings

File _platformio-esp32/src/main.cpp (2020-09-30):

// Copyright 2020 <Copyright Craft of Wari>

#include <Arduino.h>
#include <WiFi.h>
#include <Setting.h>
#include <Receiver.h>

Setting setting = Setting();
Receiver receiver = Receiver();

boolean settingFlag = false;

void setup() {
  pinMode(4 , INPUT_PULLDOWN);  // setupタクトスイッチ
  settingFlag = !!digitalRead(4);

  if (settingFlag) {
    setting.init();
  } else {
    receiver.init();
  }
}

void loop() {
  if (settingFlag) {
    setting.task();
  } else {
    receiver.task();
  }
}

/*
  ソフトウェア初回書き込み時はこの辺を動かしておいてください
  dataStore2.write("/ssid.txt","defaltssid");
  dataStore2.write("/pass.txt","defaltpass");
  dataStore2.write("/uniq.txt","defaltuniqueid");
  dataStore2.write("/cronMs.txt","30");
  dataStore2.write("/takePhoto.txt","1");
*/

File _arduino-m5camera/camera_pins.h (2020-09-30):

#if defined(CAMERA_MODEL_WROVER_KIT)
#define PWDN_GPIO_NUM    -1
#define RESET_GPIO_NUM   -1
#define XCLK_GPIO_NUM    21
#define SIOD_GPIO_NUM    26
#define SIOC_GPIO_NUM    27

#define Y9_GPIO_NUM      35
#define Y8_GPIO_NUM      34
#define Y7_GPIO_NUM      39
#define Y6_GPIO_NUM      36
#define Y5_GPIO_NUM      19
#define Y4_GPIO_NUM      18
#define Y3_GPIO_NUM       5
#define Y2_GPIO_NUM       4
#define VSYNC_GPIO_NUM   25
#define HREF_GPIO_NUM    23
#define PCLK_GPIO_NUM    22

#elif defined(CAMERA_MODEL_ESP_EYE)
#define PWDN_GPIO_NUM    -1
#define RESET_GPIO_NUM   -1
#define XCLK_GPIO_NUM    4
#define SIOD_GPIO_NUM    18
#define SIOC_GPIO_NUM    23

#define Y9_GPIO_NUM      36
#define Y8_GPIO_NUM      37
#define Y7_GPIO_NUM      38
#define Y6_GPIO_NUM      39
#define Y5_GPIO_NUM      35
#define Y4_GPIO_NUM      14
#define Y3_GPIO_NUM      13
#define Y2_GPIO_NUM      34
#define VSYNC_GPIO_NUM   5
#define HREF_GPIO_NUM    27
#define PCLK_GPIO_NUM    25

#elif defined(CAMERA_MODEL_M5STACK_PSRAM)
#define PWDN_GPIO_NUM     -1
#define RESET_GPIO_NUM    15
#define XCLK_GPIO_NUM     27
#define SIOD_GPIO_NUM     22
#define SIOC_GPIO_NUM     23

#define Y9_GPIO_NUM       19
#define Y8_GPIO_NUM       36
#define Y7_GPIO_NUM       18
#define Y6_GPIO_NUM       39
#define Y5_GPIO_NUM        5
#define Y4_GPIO_NUM       34
#define Y3_GPIO_NUM       35
#define Y2_GPIO_NUM       32
#define VSYNC_GPIO_NUM    25
#define HREF_GPIO_NUM     26
#define PCLK_GPIO_NUM     21

#elif defined(CAMERA_MODEL_M5STACK_WIDE)
#define PWDN_GPIO_NUM     -1
#define RESET_GPIO_NUM    15
#define XCLK_GPIO_NUM     27
#define SIOD_GPIO_NUM     22
#define SIOC_GPIO_NUM     23

#define Y9_GPIO_NUM       19
#define Y8_GPIO_NUM       36
#define Y7_GPIO_NUM       18
#define Y6_GPIO_NUM       39
#define Y5_GPIO_NUM        5
#define Y4_GPIO_NUM       34
#define Y3_GPIO_NUM       35
#define Y2_GPIO_NUM       32
#define VSYNC_GPIO_NUM    25
#define HREF_GPIO_NUM     26
#define PCLK_GPIO_NUM     21

#elif defined(CAMERA_MODEL_AI_THINKER)
#define PWDN_GPIO_NUM     32
#define RESET_GPIO_NUM    -1
#define XCLK_GPIO_NUM      0
#define SIOD_GPIO_NUM     26
#define SIOC_GPIO_NUM     27

#define Y9_GPIO_NUM       35
#define Y8_GPIO_NUM       34
#define Y7_GPIO_NUM       39
#define Y6_GPIO_NUM       36
#define Y5_GPIO_NUM       21
#define Y4_GPIO_NUM       19
#define Y3_GPIO_NUM       18
#define Y2_GPIO_NUM        5
#define VSYNC_GPIO_NUM    25
#define HREF_GPIO_NUM     23
#define PCLK_GPIO_NUM     22

#else
#error "Camera model not selected"
#endif

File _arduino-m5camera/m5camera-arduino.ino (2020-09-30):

#include <Arduino.h>
#include <esp_camera.h>
#include <WiFi.h>
//#include <HTTPClient.h>
#include <WiFiClientSecure.h>

#include "mbedtls/base64.h"
#include "Base64.h"
//
// WARNING!!! Make sure that you have either selected ESP32 Wrover Module,
//            or another board which has PSRAM enabled
//

// Select camera model
//#define CAMERA_MODEL_WROVER_KIT
//#define CAMERA_MODEL_ESP_EYE
#define CAMERA_MODEL_M5STACK_PSRAM
//#define CAMERA_MODEL_M5STACK_WIDE
//#define CAMERA_MODEL_AI_THINKER
//////////////////////////////

#include "camera_pins.h"

const char* ssid = "ssid";
const char* pass = "password";
const int port = 443;

const String host = "host";
String uniqueCode = "uniquecode";

String path = "/api/photos/receiver";
String method = "POST";

void startCameraServer();

void setup() {
  Serial.begin(115200);
  Serial.setDebugOutput(true);
  Serial.println("start");

  camera_config_t config;
  config.ledc_channel = LEDC_CHANNEL_0;
  config.ledc_timer = LEDC_TIMER_0;
  config.pin_d0 = Y2_GPIO_NUM;
  config.pin_d1 = Y3_GPIO_NUM;
  config.pin_d2 = Y4_GPIO_NUM;
  config.pin_d3 = Y5_GPIO_NUM;
  config.pin_d4 = Y6_GPIO_NUM;
  config.pin_d5 = Y7_GPIO_NUM;
  config.pin_d6 = Y8_GPIO_NUM;
  config.pin_d7 = Y9_GPIO_NUM;
  config.pin_xclk = XCLK_GPIO_NUM;
  config.pin_pclk = PCLK_GPIO_NUM;
  config.pin_vsync = VSYNC_GPIO_NUM;
  config.pin_href = HREF_GPIO_NUM;
  config.pin_sscb_sda = SIOD_GPIO_NUM;
  config.pin_sscb_scl = SIOC_GPIO_NUM;
  config.pin_pwdn = PWDN_GPIO_NUM;
  config.pin_reset = RESET_GPIO_NUM;
  config.xclk_freq_hz = 20000000;
  config.pixel_format = PIXFORMAT_JPEG;
  if(psramFound()){
    config.frame_size = FRAMESIZE_UXGA;
    config.jpeg_quality = 10;
    config.fb_count = 2;
  } else {
    config.frame_size = FRAMESIZE_SVGA;
    config.jpeg_quality = 12;
    config.fb_count = 1;
  }

#if defined(CAMERA_MODEL_ESP_EYE)
  pinMode(13, INPUT_PULLUP);
  pinMode(14, INPUT_PULLUP);
#endif

  // camera init
  esp_err_t err = esp_camera_init(&config);
  if (err != ESP_OK) {
    Serial.printf("Camera init failed with error 0x%x", err);
    return;
  }

  sensor_t * s = esp_camera_sensor_get();
  if (s->id.PID == OV3660_PID) {
    s->set_vflip(s, 1);  // flip it back
    s->set_brightness(s, 1);  // up the blightness just a bit
    s->set_saturation(s, -2);  // lower the saturation
  }
  // drop down frame size for higher initial frame rate
  s->set_framesize(s, FRAMESIZE_QVGA);

#if defined(CAMERA_MODEL_M5STACK_WIDE)
  s->set_vflip(s, 1);
  s->set_hmirror(s, 1);
#endif

  delay(1000);
  WiFi.begin(ssid, pass);
  Serial.print("WiFi connecting");
  int wifiCnt = 0;
  while (WiFi.status() != WL_CONNECTED) {
    if (wifiCnt == 20) {  // これ公開時は90とかにする
      Serial.print("\nWiFi restarting");
      wifiCnt = 0;
      WiFi.disconnect(true, true);
      delay(500);
      WiFi.begin(ssid, pass);
    } else {
      wifiCnt++;
      Serial.print(".");
      delay(500);
    }
  }
  Serial.println(" connected!!");

  Serial.print("Camera Ready! Use 'http://");
  Serial.print(WiFi.localIP());
  Serial.println("' to connect");

  Serial.println("take a picture");

  camera_fb_t * fb = esp_camera_fb_get();
  if(!fb) {
    Serial.println("camera error");
    return;
  }

  WiFiClientSecure client;
  Serial.print("connecting to ");
  if (!client.connect(host.c_str(), port)) {
    Serial.println("connection failed");
    return;
  }
  Serial.println("------connecting sucsess------");

  String hostStr = String(host);
  method.trim();
  hostStr.trim();
  path.trim();
  uniqueCode.trim();
  Serial.println("requesting URL: " + hostStr + path + "/"+uniqueCode+"/");

  String pic = base64::encode(fb->buf, fb->len).c_str();
  int wordCount = 1800;
  int len = pic.length()/wordCount;
  if (pic.length()%wordCount) len++;
  int cnt = 0;
  while (pic.length()) {
    cnt++;
    String d = pic.substring(0, wordCount);
    pic.remove(0, wordCount);

    String req =
    method + " " + path + "/"+ uniqueCode + "/" + cnt + "/" + len + "/" + d + " HTTP/1.1\r\n" +
    "Host: " + hostStr + "\r\n" +
    "User-Agent: ESP\r\n" +  // "User-Agent: curl/7.47.0\r\n" +
    "Accept: */*\r\n" +
    "Expect: 100-continue \r\n"+
    "\r\n\r\n";

    client.print(req);
    Serial.println(req);
  }
  client.flush();
  Serial.println("request send");

  Serial.println("----------------------------");
  Serial.println("header");
  while (client.connected()) {
    String line = client.readStringUntil('\n');
    Serial.println(line);
    if (line == "\r") {
      Serial.println("headers received");
      Serial.println("----------------------------");
      break;
    }
  }

  Serial.println("==========");
  Serial.println(client.readString());
  Serial.println("==========");
  client.stop();
}

void loop() {
}

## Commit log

2020-09-27 Pin dependencies
2020-09-29 :construction: add: printting status info
2020-09-30 :sparkles: add: the feature to send the ip address
    [2Suppress.stl, CCC2020 SmartPostBox PARTS.xlsx, DCDC.stl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]
2020-10-05 Update codeql-analysis.yml
    Remove CPP checking because it's the Arduino language.
2020-10-05 Update dependency @slack/bolt to v2.4.1
2020-10-05 :green_heart: fix: the name of script for migration on CI
    [Http.cpp]
2020-10-13 :white_check_mark: updated: automatic switching to sqlite when testing
2020-11-25 Update dependency @slack/bolt to v2.5.0
2021-01-12 Update dependency @slack/bolt to v2.7.0
2021-03-25 Update dependency @slack/bolt to v3
2021-07-13 Update dependency @slack/bolt to v3.4.1
2021-07-23 Update dependency @slack/bolt to v3.5.0

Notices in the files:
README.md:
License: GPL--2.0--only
